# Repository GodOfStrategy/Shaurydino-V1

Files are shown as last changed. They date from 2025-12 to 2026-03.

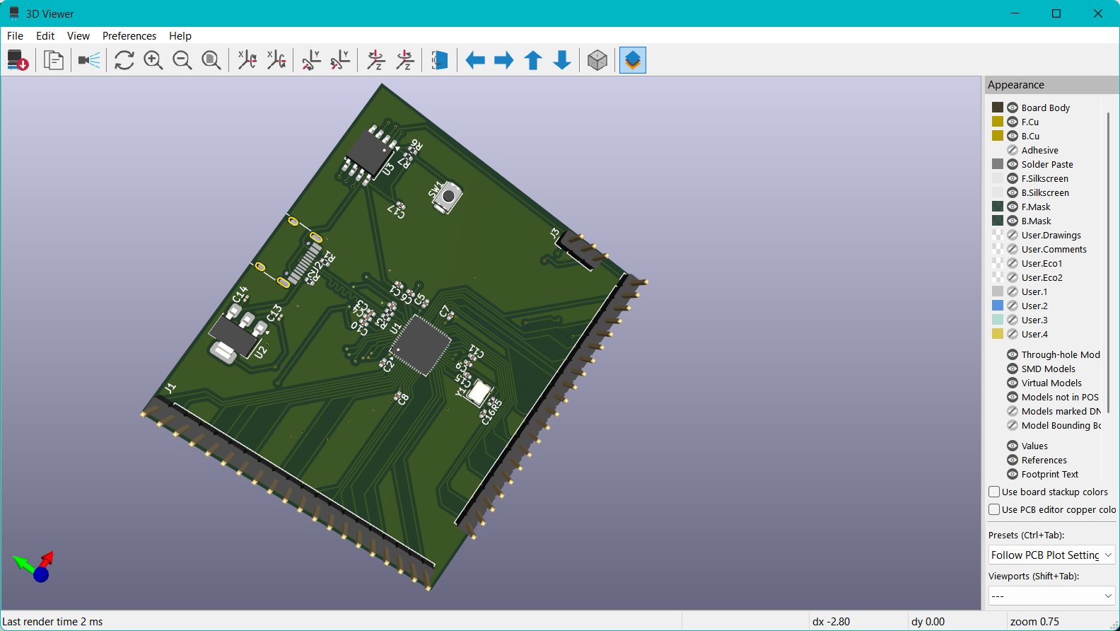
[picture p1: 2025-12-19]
Screenshot 2025-12-19 182844.png

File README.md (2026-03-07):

# Shaurdino-V1
A custom devboard tailored for small and medium applications.
I plan to use it to efficiently reduce electricity consumption in a voice recorder and announcer module of my own.

Key Features
Core MCU:

Raspberry Pi RP2040 dual‑core ARM Cortex‑M0+ processor.

Connected to a 12 MHz crystal oscillator for precise clocking.

USB Interface:

USB‑C connector with ESD protection (USBLC6‑2SC6).

NCP-1117 linear voltage regulator providing a clean 3.3 V rail.

Decoupling capacitors distributed across the board for stable supply.

Designed to accept 5 V from USB or a regulated external source.

Memory:

W25Q32JVSS QSPI flash for program and data storage.

Connected via dedicated QSPI pins for high‑speed access.

Connectivity & Expansion:

Dual 20‑pin headers, exposing GPIO0–GPIO29, ADC inputs, and power rails for running peripherals safely.

Breakout for SWCLK and SWDIO debug signals.

RUN pin with pull‑up for reset control.

Supporting Components:

Crystal oscillator network with capacitors and resistor for stable timing.

Multiple capacitors (C1–C17, C36–C39) for filtering and decoupling higher frequency  and low frequency smoothning.

Resistors for pull‑ups/pull‑downs and configuring certain components.

Here is the 3D model of my PCB.


You can find the schematics in the repository as well as the PCB design and it's Gerber files.
Here are the PCB and Schematics Images for your reference here aswell:



The BOM for the project- 


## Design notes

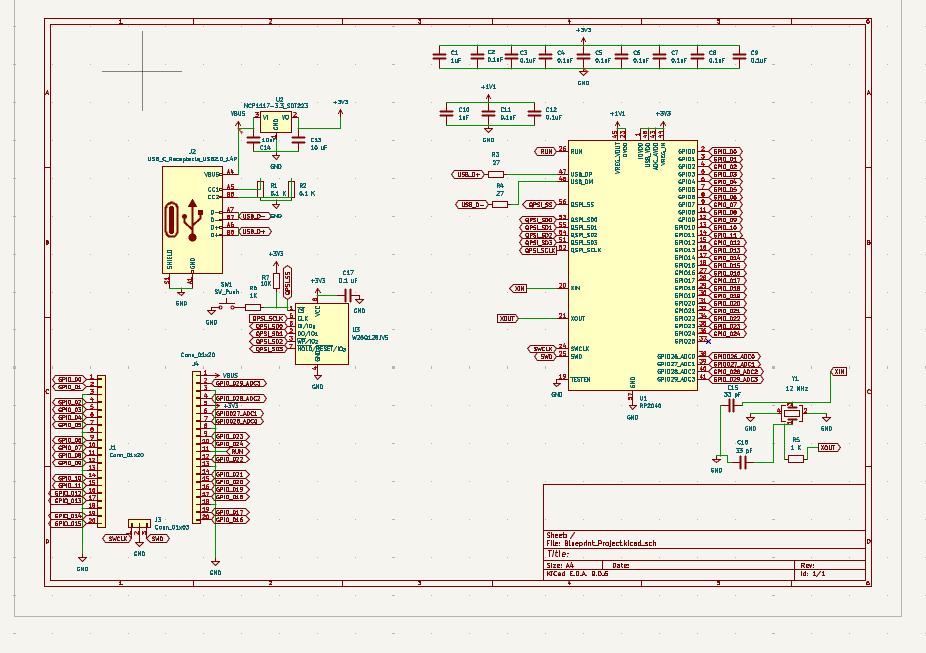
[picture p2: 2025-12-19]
Screenshot 2025-12-13 184159.png

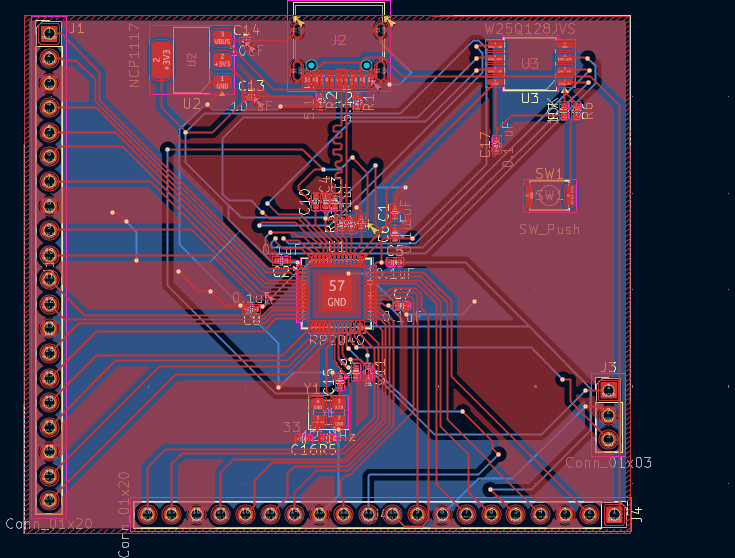
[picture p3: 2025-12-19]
Screenshot 2025-12-17 222851.png

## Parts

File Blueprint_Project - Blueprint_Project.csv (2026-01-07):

Designator | Footprint | Quantity | Comment | Price ($- USD) | Datasheet
C1,C10 | Capacitor_SMD:C_0402_1005Metric | 2 | 1uF | 0.06 | ~
C2,C3,C4,C5,C6,C7,C8,C9,C11,C12,C17 | Capacitor_SMD:C_0402_1005Metric | 10 | 0.1uF | 0.04 | ~
C14, C13 | Capacitor_SMD:C_0201_0603Metric | 1 | 10uF | 0.11 | ~
C15,C16 | Capacitor_SMD:C_0402_1005Metric | 2 | 33 pF | 0.02 | ~
J1,J4 | Connector_PinHeader_2.54mm:PinHeader_1x20_P2.54mm_Vertical | 2 | Conn_01x20 | nil | ~
J2 | Connector_USB:USB_C_Receptacle_HRO_TYPE-C-31-M-12 | 1 | USB_C_Receptacle_USB2.0_14P | 0.34 | https://www.usb.org/sites/default/files/documents/usb_type-c.zip
J3 | Connector_PinHeader_2.54mm:PinHeader_1x03_P2.54mm_Vertical | 1 | Conn_01x03 | nil | ~
R1,R2 | Resistor_SMD:R_0402_1005Metric | 2 | 5.1 K | 0.01 | ~
R3,R4 | Resistor_SMD:R_0402_1005Metric | 2 | 27 | 0.01 | ~
R6, R5 | Resistor_SMD:R_0402_1005Metric | 1 | 1K | 0.01 | ~
R7 | Resistor_SMD:R_0402_1005Metric | 1 | 10K | 0.01 | ~
SW1 | Button_Switch_SMD:SW_Push_SPST_NO_Alps_SKRK | 1 | SW_Push | 0.26 | ~
U1 | Package_DFN_QFN:QFN-56-1EP_7x7mm_P0.4mm_EP3.2x3.2mm | 1 | RP2040 | 1.86 | https://datasheets.raspberrypi.com/rp2040/rp2040-datasheet.pdf
U2 | Package_TO_SOT_SMD:SOT-223-3_TabPin2 | 1 | NCP1117-3.3_SOT223 | 0.46 | http://www.onsemi.com/pub_link/Collateral/NCP1117-D.PDF
U3 | Package_SO:SOIC-8_5.3x5.3mm_P1.27mm | 1 | W25Q128JVS | 3.01 | https://www.winbond.com/resource-files/w25q128jv_dtr%20revc%2003272018%20plus.pdf
Y1 | Crystal:Crystal_SMD_3225-4Pin_3.2x2.5mm | 1 | 12 MHz | 0.4 | ~

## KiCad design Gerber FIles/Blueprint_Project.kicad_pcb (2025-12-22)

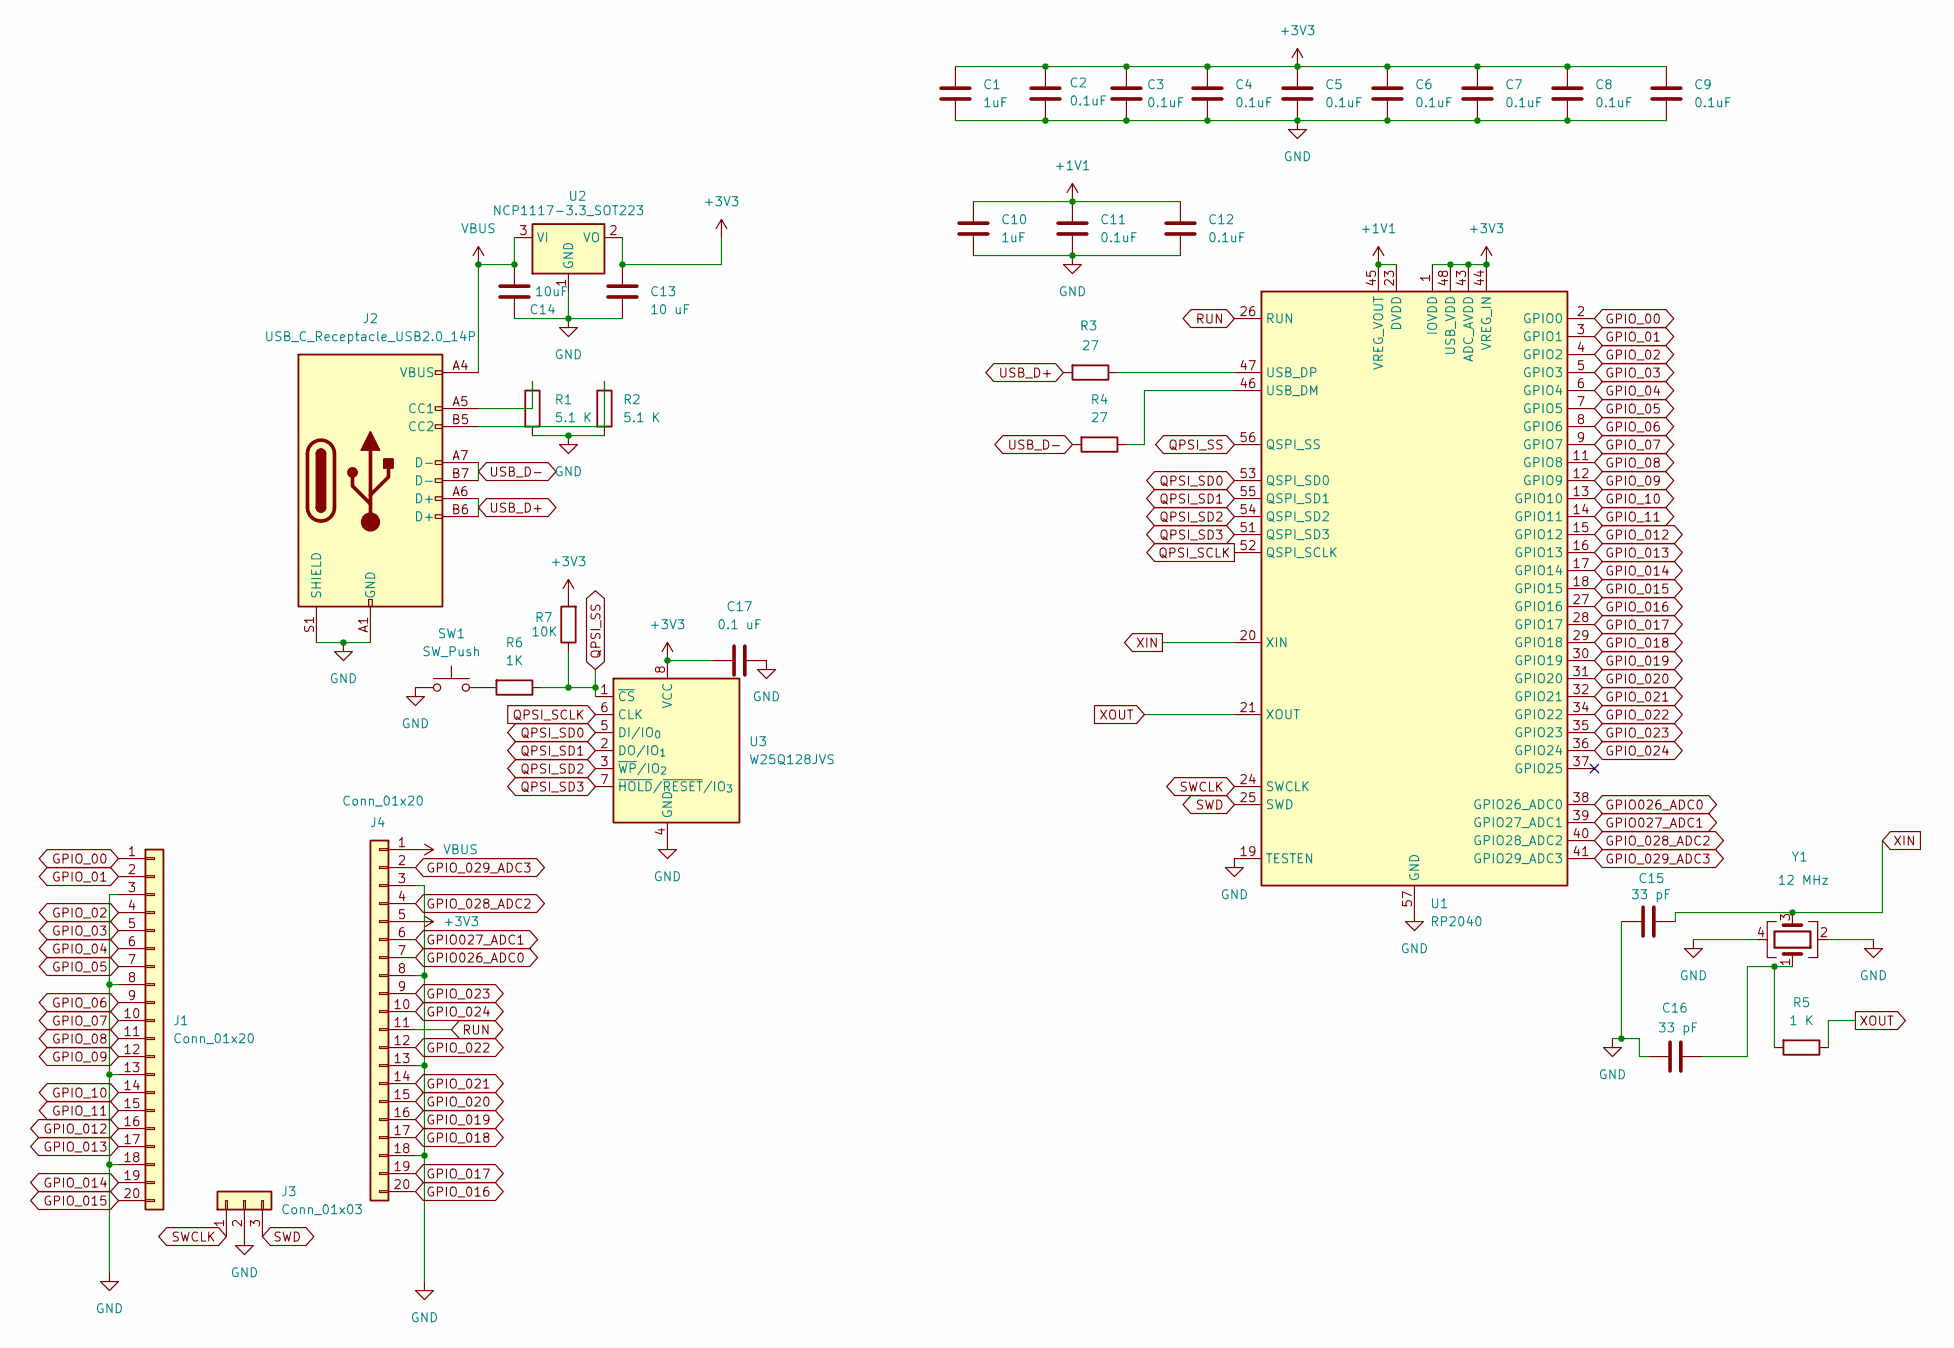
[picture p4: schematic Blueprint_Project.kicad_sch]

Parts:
C1, C10: 1uF; C_0402_1005Metric
C2, C3, C4, C5, C6, C7, C8, C9, C11, C12: 0.1uF; C_0402_1005Metric
C13: 10 uF; C_0201_0603Metric
C14: 10uF; C_0201_0603Metric
C15, C16: 33 pF; C_0402_1005Metric
C17: 0.1 uF; C_0402_1005Metric
J1, J4: Conn_01x20; PinHeader_1x20_P2.54mm_Vertical
J2: USB_C_Receptacle_USB2.0_14P; USB_C_Receptacle_HRO_TYPE-C-31-M-12
J3: Conn_01x03; PinHeader_1x03_P2.54mm_Vertical
R1, R2: 5.1 K; R_0402_1005Metric
R3, R4: 27; R_0402_1005Metric
R5: 1 K; R_0402_1005Metric
R6: 1K; R_0402_1005Metric
R7: 10K; R_0402_1005Metric
SW1: SW_Push; SW_Push_SPST_NO_Alps_SKRK
U1: RP2040; QFN-56-1EP_7x7mm_P0.4mm_EP3.2x3.2mm
U2: NCP1117-3.3_SOT223; SOT-223-3_TabPin2
U3: W25Q128JVS; SOIC-8_5.3x5.3mm_P1.27mm
Y1: 12 MHz; Crystal_SMD_3225-4Pin_3.2x2.5mm

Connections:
+1V1: C10.1, C11.1, C12.1, U1.23 (DVDD), U1.45 (VREG_VOUT), U1.50 (DVDD)
+3V3: C1.1, C2.1, C3.1, C4.1, C5.1, C6.1, C7.1, C8.1, C9.1, C13.1, C17.2, J4.5, R7.2, U1.1 (IOVDD), U1.10 (IOVDD), U1.22 (IOVDD), U1.33 (IOVDD), U1.42 (IOVDD), U1.43 (ADC_AVDD), U1.44 (VREG_IN), U1.48 (USB_VDD), U1.49 (IOVDD), U2.2 (VO), U3.8 (VCC)
GND: C1.2, C2.2, C3.2, C4.2, C5.2, C6.2, C7.2, C8.2, C9.2, C10.2, C11.2, C12.2, C13.2, C14.2, C15.2, C16.2, C17.1, J1.3, J1.8, J1.13, J1.18, J2.A1 (GND), J2.A12 (GND), J2.B1 (GND), J2.B12 (GND), J2.S1 (SHIELD), J3.2, J4.3, J4.8, J4.13, J4.18, R1.2, R2.2, SW1.1, U1.19 (TESTEN), U1.57 (GND), U2.1 (GND), U3.4 (GND), Y1.2, Y1.4
GPIO026_ADC0: J4.7, U1.38 (GPIO26_ADC0)
GPIO027_ADC1: J4.6, U1.39 (GPIO27_ADC1)
GPIO_00: J1.1, U1.2 (GPIO0)
GPIO_01: J1.2, U1.3 (GPIO1)
GPIO_02: J1.4, U1.4 (GPIO2)
GPIO_03: J1.5, U1.5 (GPIO3)
GPIO_04: J1.6, U1.6 (GPIO4)
GPIO_05: J1.7, U1.7 (GPIO5)
GPIO_06: J1.9, U1.8 (GPIO6)
GPIO_07: J1.10, U1.9 (GPIO7)
GPIO_08: J1.11, U1.11 (GPIO8)
GPIO_09: J1.12, U1.12 (GPIO9)
GPIO_10: J1.14, U1.13 (GPIO10)
GPIO_11: J1.15, U1.14 (GPIO11)
GPIO_012: J1.16, U1.15 (GPIO12)
GPIO_013: J1.17, U1.16 (GPIO13)
GPIO_014: J1.19, U1.17 (GPIO14)
GPIO_015: J1.20, U1.18 (GPIO15)
GPIO_016: J4.20, U1.27 (GPIO16)
GPIO_017: J4.19, U1.28 (GPIO17)
GPIO_018: J4.17, U1.29 (GPIO18)
GPIO_019: J4.16, U1.30 (GPIO19)
GPIO_020: J4.15, U1.31 (GPIO20)
GPIO_021: J4.14, U1.32 (GPIO21)
GPIO_022: J4.12, U1.34 (GPIO22)
GPIO_023: J4.9, U1.35 (GPIO23)
GPIO_024: J4.10, U1.36 (GPIO24)
GPIO_028_ADC2: J4.4, U1.40 (GPIO28_ADC2)
GPIO_029_ADC3: J4.2, U1.41 (GPIO29_ADC3)
unnamed: C16.1, R5.2, Y1.1
unnamed: J2.A5 (CC1), R1.1
unnamed: J2.B5 (CC2), R2.1
unnamed: R6.2, SW1.2
unnamed: R4.1, U1.46 (USB_DM)
unnamed: R3.1, U1.47 (USB_DP)
QPSI_SCLK: U1.52 (QSPI_SCLK), U3.6 (CLK)
QPSI_SD0: U1.53 (QSPI_SD0), U3.5 (DI/IO_{0})
QPSI_SD1: U1.55 (QSPI_SD1), U3.2 (DO/IO_{1})
QPSI_SD2: U1.54 (QSPI_SD2), U3.3 (~WP/IO_{2})
QPSI_SD3: U1.51 (QSPI_SD3), U3.7 (~HOLD/~RESET/IO_{3})
QPSI_SS: R6.1, R7.1, U1.56 (QSPI_SS), U3.1 (~CS)
RUN: J4.11, U1.26 (RUN)
SWCLK: J3.1, U1.24 (SWCLK)
SWD: J3.3, U1.25 (SWD)
USB_D+: J2.A6 (D+), J2.B6 (D+), R3.2
USB_D-: J2.A7 (D-), J2.B7 (D-), R4.2
VBUS: C14.1, J2.A4 (VBUS), J2.A9 (VBUS), J2.B4 (VBUS), J2.B9 (VBUS), J4.1, U2.3 (VI)
XIN: C15.1, U1.20 (XIN), Y1.3
XOUT: R5.1, U1.21 (XOUT)

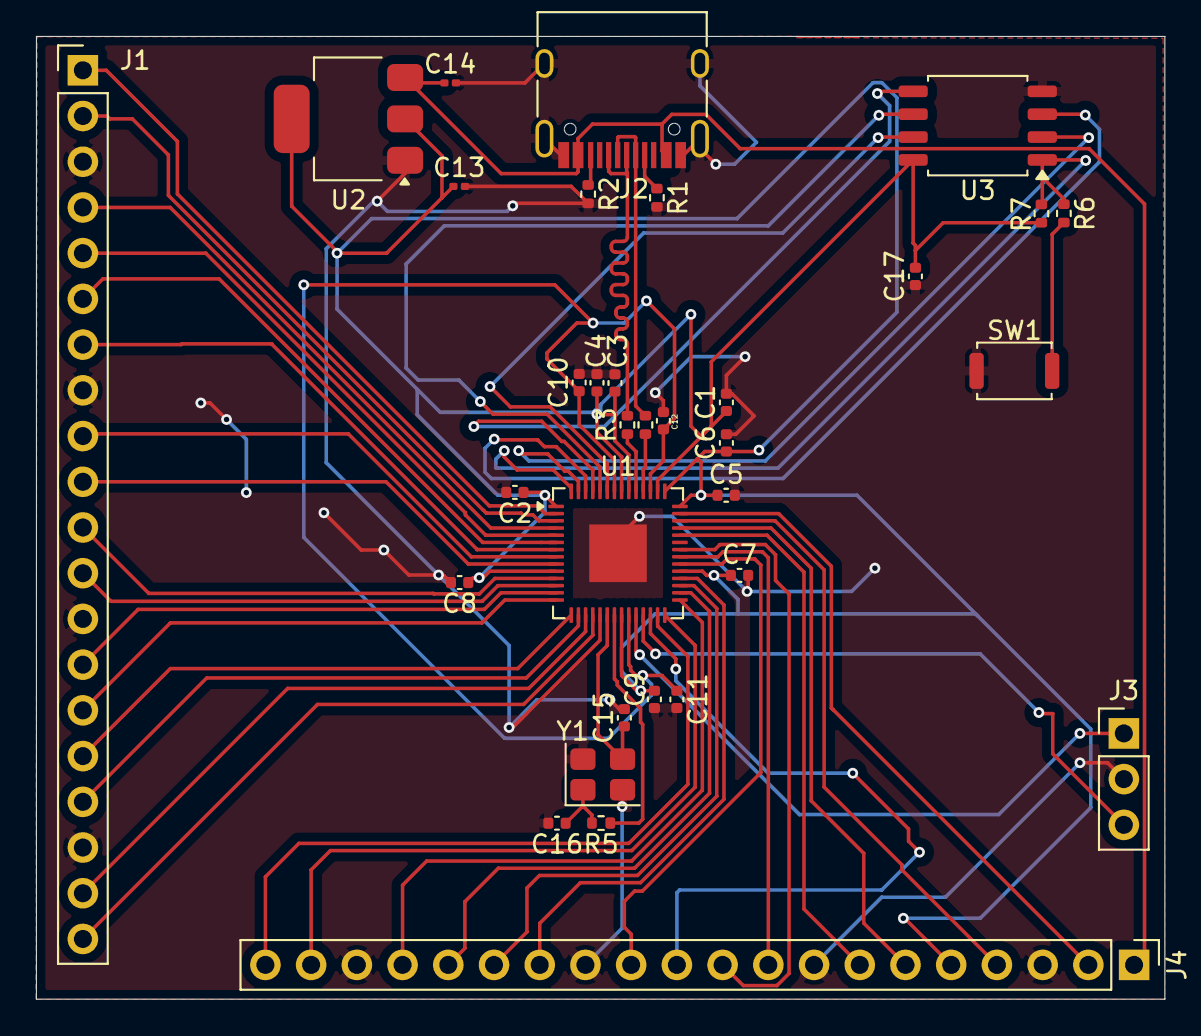
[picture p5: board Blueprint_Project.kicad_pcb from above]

Board: 2 copper layers, 62.7 x 53.5 mm, 33 parts (0 on the bottom side), 52 nets.

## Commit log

2025-12-19 ReadMe
    README file for the board
2025-12-19 Update print statement from 'Hello' to 'Goodbye'
2026-02-17 Update BOM section with additional image
    Added an image to the BOM section and improved formatting.
